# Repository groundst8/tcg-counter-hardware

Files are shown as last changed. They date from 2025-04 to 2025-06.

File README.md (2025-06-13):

# TCG Counter Hardware

## Components

[TI RF430FRL152H](https://www.ti.com/lit/ds/symlink/rf430frl152h.pdf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)
- ISO 15693
- NfcV
- 1.5V passivey powered
- 8 bit GPIO
- I2c
- +/- 400 uA GPIO current, 500 uA max all I/O 0.15V voltage drop

[Ynvisible D0432G02V01](https://assets-global.website-files.com/5f7f21e12602d912658dce12/62207f04e89fc72369fa582a_D0432G02V01-V1.0.pdf)
- 7 Segment E-Paper Display
- +/- 1.5V operating voltage
- 0.81 uA steady state current, all segments on
- ~3.25 mA (datasheet says 2.92 mA) peak current all segments; ~1.25 mA peak / segment

[TI TCAL9539](https://www.ti.com/lit/ds/symlink/tcal9539.pdf)
- Low-Voltage 16-Bit I2c Expander
- I/Os backpowered protected

## Constraints

### Harvested Power

Table 4 from [Frequently asked questions for RF430FRL15xH devices](https://www.ti.com/lit/an/sloa247c/sloa247c.pdf) shows the maximum harvested power available when using the using the TRF7970AEVM with a 5-V power supply as the tag reader. It is also mentioned that the current that can be supplied depends on the reader distance to the tag. 



## Ynvisible Display Testing

Twenty minute timelapse test to evaluation if the Ynvisible 7 segment display keeps readable contrast over a 20 minute period without power. Twenty minutes was chosen as the upper end of how long a counter would go without being updated. Twenty minutes is the length of the average Magic The Gathering standard format game. Commander games go longer but generally counters are updated over the course of the game which would provide the refresh without requiring additional effort.

YouTube (https://www.youtube.com/watch?v=dayQ5Arc0Ek)

## Development Board Prototyping

### Iteration 1

dev_board

- GoodTag11
  - Open source hardware design
  - PCB & SMT assembly by JLCPCB
  - Through hole headers hand soldered by yours truly
- Ynvisible E-Paper Display Kit Adapter

#### Issues
- E-paper display backpowering RF430FRL152H via GPIO ESD diodes in no power state
  - GPIOs do not remain high-Z and display loses contrast
- TimerA0 low power delays not working in ROM patch operating mode
  - Temporarily doing delays on smartphone side
 
## Iteration 2



- Put two 4 channel TMUX1511 analog switches between GPIOs and display
  - Enabled when have power and disabled when no power is applied
  - Fixes display contrast loss issue from Iteration 1

#### Issues
- GPIO Port1.7 is used by ROM code to indicate operating mode and doesn't seem available for display use in ROM patch mode
- Ultimately would be more useful with two 7 segment digits, could potentially use single chip TCAL9539 GPIO expanded that should also remain high-Z with no power
  - Would be fewer parts than the TMUX1511 solution and give greater capability
- Peak current consumption of display was more than anticiapted per segment
  - Look into handling larger peak current with appropriately sized capacitor

Ynvisible provided segment switching current decay curves which are shown below modeled with exponential decay functions. The raw data is available in 1vs7segs.xlsx. I was anticipating the single segment switching current to be lower so will need to do some additional testing and measurement to determine if enough energy will be harvested to do the switching.

ynvisible

## Iteration 3



- Switched to RF430FRL152HEVM dev board
  - Can program with MSP-FET programmer via JTAG
  - Work around issue programming GoodTag11 with GoodV over the air not working with NFC only ROM firmware
- Switched from TMUX1511s to TCAL9539 for GPIO expansion and backpower protection
- Switched to Ynvisible 2 digit 7 segment display

#### Issues
- Currently powered from MSP-FET source
  - Need to do testing and see if can find solution to passively power from RF field in a way that is economically viable
- Need to get JTAG level transalation working so can switch back to GoodTag11 and custom PCB instead of dev board and use MSP-FET programmer

## Iteration 4



- Switched back to GoodTag11 from RF430FRL152HEVM dev board
- JTAG Level Translation & JTAG debugging working
  - Using SN74AXC4T774 Evaluation Module with TCK, TDI, TMS, TDO, and RST signals 3.3v <-> 1.5v
  - Replaced some 10pF capacitors that should have been 10nF and were preventing JTAG debugging from working
- EnergyTrace working

energy_trace_plot

#### Issues
- Evaluate passive power ability to drive display
- Complete PCB layouts for mainboard and JTAG translation board

## Iteration 5 - v1.0.0

### JLCPCB PCB with rails/fiducials for assembly



### Board with display attached and functioning


#### Issues
- Forgot pull-up resistors for RESET and INT pins on TCAL
- Firmware updating all segments in parallel is causing brownouts, look into sequential segment updating

## Electrical Engineering

[Jupyter Notebook](display.ipynb)

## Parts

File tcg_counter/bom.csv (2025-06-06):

Reference | Value | Datasheet | Footprint | Qty | DNP
C1,C3,C4,C5 | 100nF | ~ | Capacitor_SMD:C_0402_1005Metric | 4
C2 | 2.2µF | ~ | Capacitor_SMD:C_0402_1005Metric | 1
C6,C7 | 10nF | ~ | Capacitor_SMD:C_0402_1005Metric | 2
C8 | 91pF | ~ | Capacitor_SMD:C_0402_1005Metric | 1
C9 | 1µF | ~ | Capacitor_SMD:C_0402_1005Metric | 1
C10 | DNP | ~ | Capacitor_SMD:C_0402_1005Metric | 1
C11 | 1uF | ~ | Capacitor_SMD:C_0402_1005Metric | 1
C12 | 0.1uF | ~ | Capacitor_SMD:C_0402_1005Metric | 1
DS1 | ~ |  | Library:D0430G02V01 | 1
L1 | Antenna | ~ | footprints:GW10ANT | 1
P1 | TC2050-IDC-430 |  | Connector:Tag-Connect_TC2050-IDC-NL_2x05_P1.27mm_Vertical_with_bottom_clip | 1
R1 | 0 | ~ | Resistor_SMD:R_0402_1005Metric | 1
R2,R3 | 10k | ~ | Resistor_SMD:R_0402_1005Metric | 2
U1 | TCAL9539RTW | http://www.ti.com/lit/ds/symlink/tca9539.pdf | TIFootprints:TI_RTW24_4x4mm_EP2.2mm | 1
U2 | RF430FRL152 | http://www.ti.com/lit/ds/symlink/rf430frl152h.pdf | footprints:RF430FRL152H | 1

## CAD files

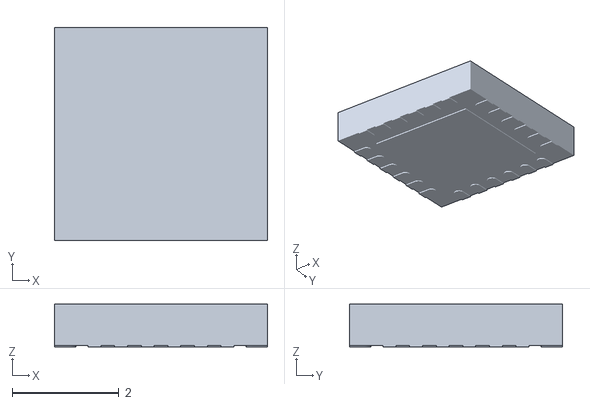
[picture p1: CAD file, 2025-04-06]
tcg_counter/TCAL9539RTWR/RTW0024H.stl
4.00 x 4.00 x 0.8

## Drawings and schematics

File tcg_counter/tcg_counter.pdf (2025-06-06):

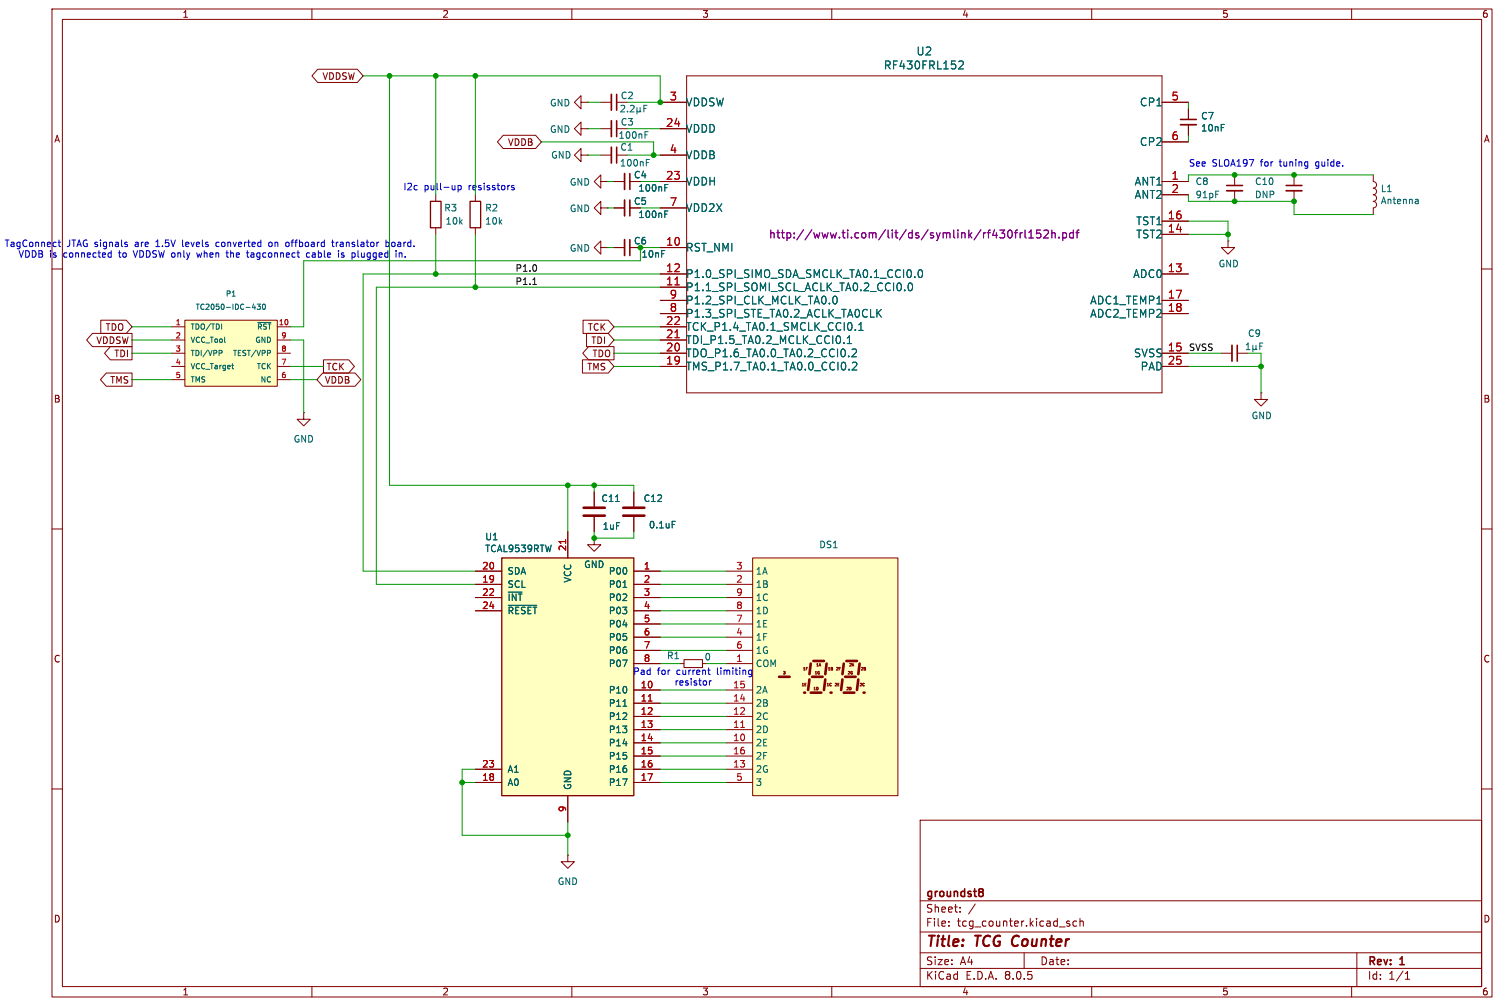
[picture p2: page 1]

http://www.ti.com/lit/ds/symlink/rf430frl152h.pdf C3

See SLOA197 for tuning guide.

Id: 1/1 Title: TCG Counter File: tcg_counter.kicad_sch Sheet: / groundst8

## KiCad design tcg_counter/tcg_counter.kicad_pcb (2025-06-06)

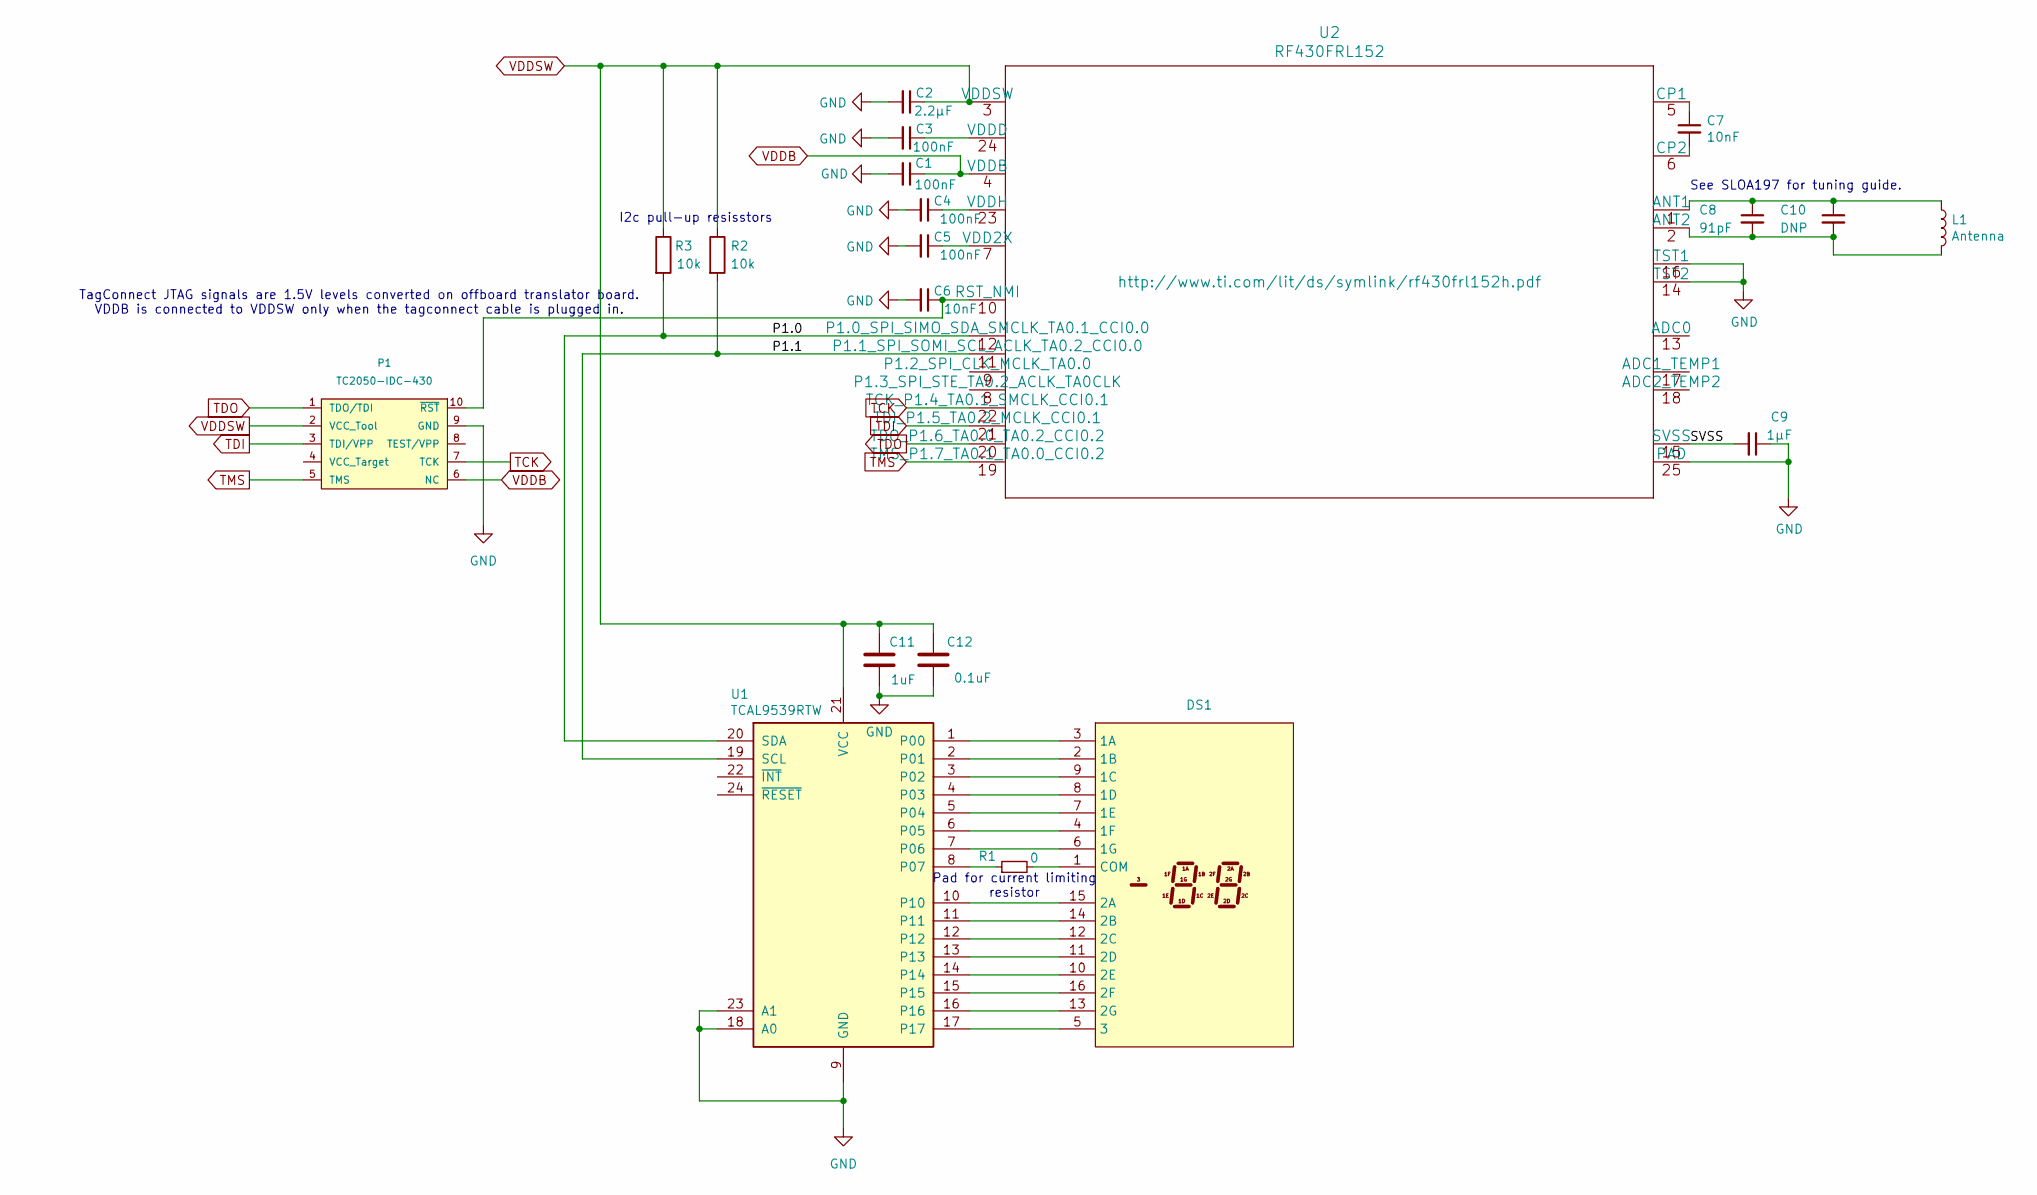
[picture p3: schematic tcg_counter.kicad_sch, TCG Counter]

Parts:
C1, C3, C4, C5: 100nF; C_0402_1005Metric
C2: 2.2µF; C_0402_1005Metric
C6, C7: 10nF; C_0402_1005Metric
C8: 91pF; C_0402_1005Metric
C9: 1µF; C_0402_1005Metric
C10: DNP; C_0402_1005Metric
C11: 1uF; C_0402_1005Metric
C12: 0.1uF; C_0402_1005Metric
DS1: D0430G02V01
L1: Antenna; GW10ANT
P1: TC2050-IDC-430; Tag-Connect_TC2050-IDC-NL_2x05_P1.27mm_Vertical_with_bottom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
R1: 0; R_0402_1005Metric
R2, R3: 10k; R_0402_1005Metric
U1: TCAL9539RTW; TI_RTW24_4x4mm_EP2.2mm
U2: RF430FRL152; RF430FRL152H

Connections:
/P1.0: R3.2, U1.20 (SDA), U2.12 (P1.0_SPI_SIMO_SDA_SMCLK_TA0.1_CCI0.0)
/P1.1: R2.2, U1.19 (SCL), U2.11 (P1.1_SPI_SOMI_SCL_ACLK_TA0.2_CCI0.0)
/SVSS: C9.2, U2.15 (SVSS)
GND: C1.2, C2.2, C3.2, C4.2, C5.2, C6.2, C9.1, C11.2, C12.2, P1.9 (GND), U1.9 (GND), U1.18 (A0), U1.23 (A1), U1.25, U2.14 (TST2), U2.16 (TST1), U2.25 (PAD)
unnamed: DS1.3 (1A), U1.1 (P00)
unnamed: DS1.2 (1B), U1.2 (P01)
unnamed: DS1.9 (1C), U1.3 (P02)
unnamed: DS1.8 (1D), U1.4 (P03)
unnamed: DS1.7 (1E), U1.5 (P04)
unnamed: DS1.4 (1F), U1.6 (P05)
unnamed: DS1.6 (1G), U1.7 (P06)
unnamed: DS1.15 (2A), U1.10
unnamed: DS1.14 (2B), U1.11
unnamed: DS1.12 (2C), U1.12
unnamed: DS1.11 (2D), U1.13
unnamed: DS1.10 (2E), U1.14
unnamed: DS1.16 (2F), U1.15
unnamed: DS1.13 (2G), U1.16
unnamed: DS1.5 (3), U1.17
unnamed: DS1.1 (COM), R1.2
unnamed: C6.1, P1.10 (~RST), U2.10 (RST_NMI)
unnamed: R1.1, U1.8 (P07)
unnamed: C8.1, C10.1, L1.1, U2.1 (ANT1)
unnamed: C8.2, C10.2, L1.2, U2.2 (ANT2)
unnamed: C7.1, U2.5 (CP1)
unnamed: C7.2, U2.6 (CP2)
unnamed: C5.1, U2.7 (VDD2X)
unnamed: C3.1, U2.24 (VDDD)
unnamed: C4.1, U2.23 (VDDH)
TCK: P1.7 (TCK), U2.22 (TCK_P1.4_TA0.1_SMCLK_CCI0.1)
TDI: P1.3 (TDI/VPP), U2.21 (TDI_P1.5_TA0.2_MCLK_CCI0.1)
TDO: P1.1 (TDO/TDI), U2.20 (TDO_P1.6_TA0.0_TA0.2_CCI0.2)
TMS: P1.5 (TMS), U2.19 (TMS_P1.7_TA0.1_TA0.0_CCI0.2)
VDDB: C1.1, P1.6 (NC), U2.4 (VDDB)
VDDSW: C2.1, C11.1, C12.1, P1.2 (VCC_Tool), R2.1, R3.1, U1.21 (VCC), U2.3 (VDDSW)

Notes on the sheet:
Pad for current limiting resistor
I2c pull-up resisstors
TagConnect JTAG signals are 1.5V levels converted on offboard translator board. VDDB is connected to VDDSW only when the tagconnect cable is plugged in.
See SLOA197 for tuning guide.

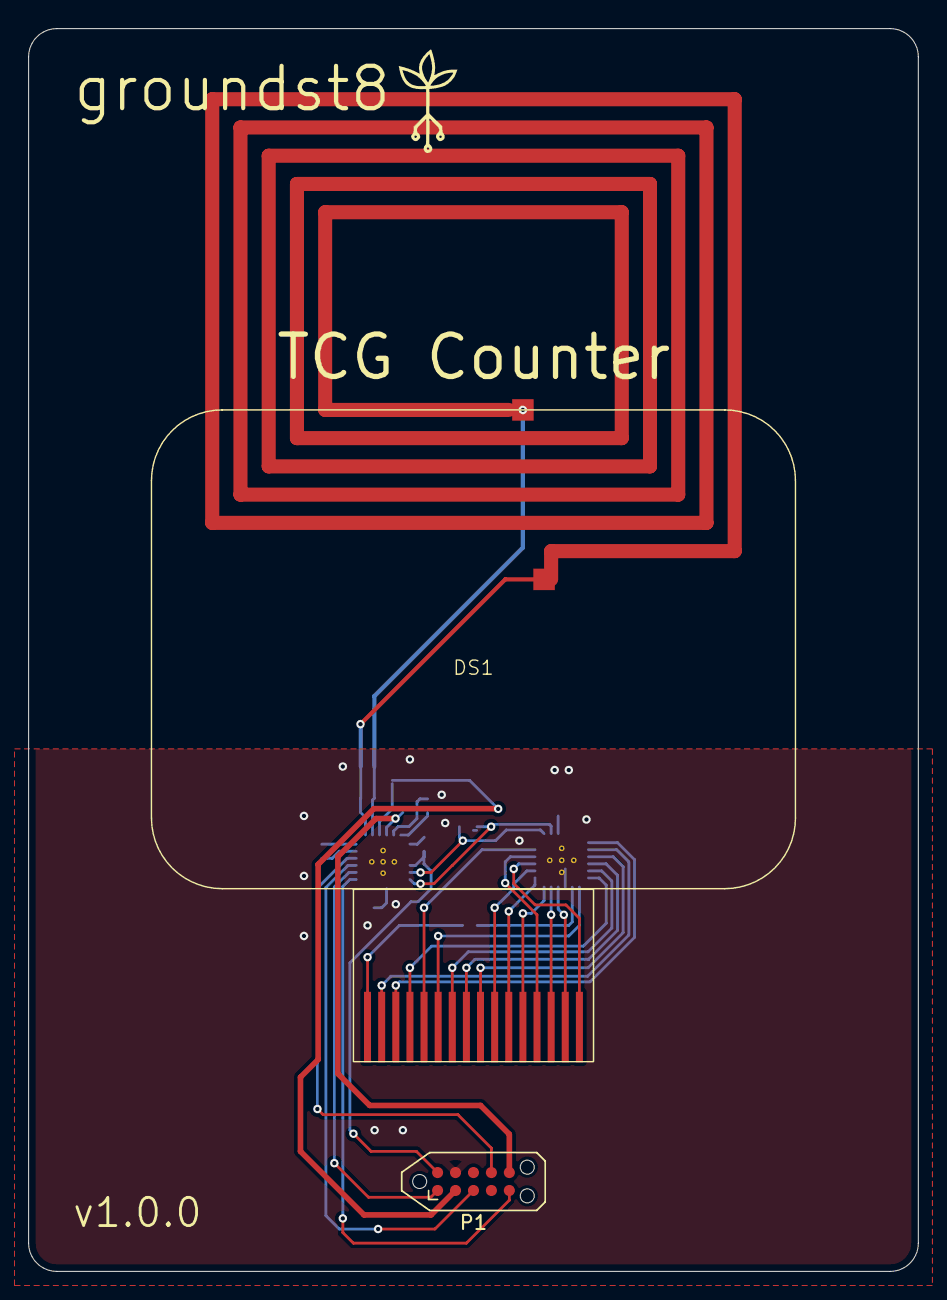
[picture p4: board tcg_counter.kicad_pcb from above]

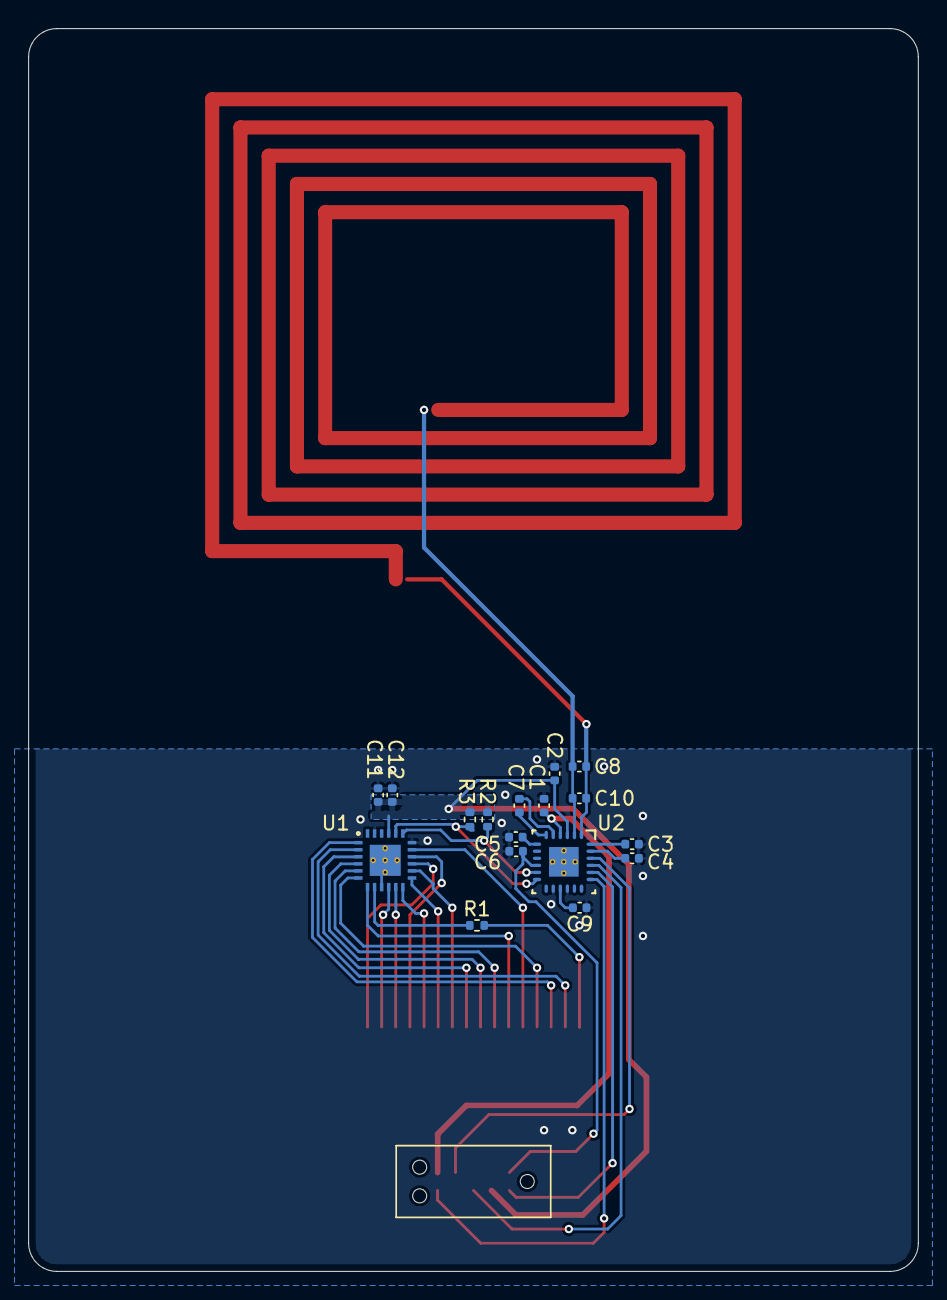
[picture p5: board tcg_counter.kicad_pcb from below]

Board: 2 copper layers, 63.0 x 88.0 mm, 20 parts (17 on the bottom side), 35 nets.

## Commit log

2024-06-21 Added I2C chip
2024-07-18 Added development board prototyping section
2024-10-13 Add empty kicad project
    [tcg_counter.kicad_pcb, tcg_counter.kicad_sch]
2024-10-13 Mess around with qr code on silkscreen
    [tcg_counter.kicad_pcb]
2024-10-13 Added contacts for display
    [tcg_counter.kicad_pcb]
2024-10-19 Added dispay symbol to schematic and update TCAL9539
    [tcg_counter.kicad_pcb, tcg_counter.kicad_sch]
2024-10-27 Added display segment switching current curves
2024-10-27 Added harvested power constraint section
2024-11-10 Added current decay plot
2024-11-10 Added display current measurements raw data
    [1vs7segs.xlsx]
2025-01-21 Added antenna trace from goodtag
    [tcg_counter-B_Cu.gbr, tcg_counter-B_Mask.gbr, tcg_counter-B_Paste.gbr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]
2025-02-12 Removed QR code
    [tcg_counter.kicad_pcb]
2025-03-07 Added notebook for ynvisible current curves
2025-03-08 Added current limiting resistor
    [tcg_counter.kicad_pcb, tcg_counter.kicad_sch]
2025-03-08 Removed old p1.2 and p1.3 header connections
    [tcg_counter.kicad_sch]
2025-03-09 Added decoupling capacitors on TCAL9539RTW
    [tcg_counter.kicad_sch]
2025-03-10 Assigned footprints
    [tcg_counter.kicad_pcb, tcg_counter.kicad_sch]
2025-04-06 Work on pcb layout, added no fill zones
    [RTW0024H.stl, bom.csv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]
2025-04-20 Added tagconnect power signals
    [tcg_counter.kicad_sch]
2025-04-20 Routing to antenna and some capacitors
    [tcg_counter-B_Cu.gbr, tcg_counter-B_Mask.gbr, tcg_counter-B_Paste.gbr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]
2025-05-24 Finished traces, made new footprint for TCAL9539
    [tcg_counter-B_Cu.gbr, tcg_counter-B_Mask.gbr, tcg_counter-B_Paste.gbr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]
2025-05-25 Cleaned up pad vias and solder paste
    [tcg_counter-B_Cu.gbr, tcg_counter-B_Mask.gbr, tcg_counter-B_Paste.gbr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]
2025-06-06 v1.0 hardware revision
    [bom.csv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]
